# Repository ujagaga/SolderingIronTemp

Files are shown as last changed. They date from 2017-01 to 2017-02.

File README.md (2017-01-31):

# SolderingIronTemp

I made a simple circuit to controll GORDAK soldering iron temperature. I figured I don't really need excessive precision 
since I don't really notice much difference between 350 and 380 degrees when soldering and I only use two positions anyway,
colder for small SMDs and hotter for more massive pieces. i am very happy with how this works and it is extreemly cheap.
The PCB is made for DOT PCB Perfboard (2.5mm holle dostance) so no PCB printing is necessary. Resistors and capacitors are SMD 0805 and they fit 
nicelly between two dots and under the OpAmp.

The schematic and PCB was done in KiCad, but you can just use the PNG images.

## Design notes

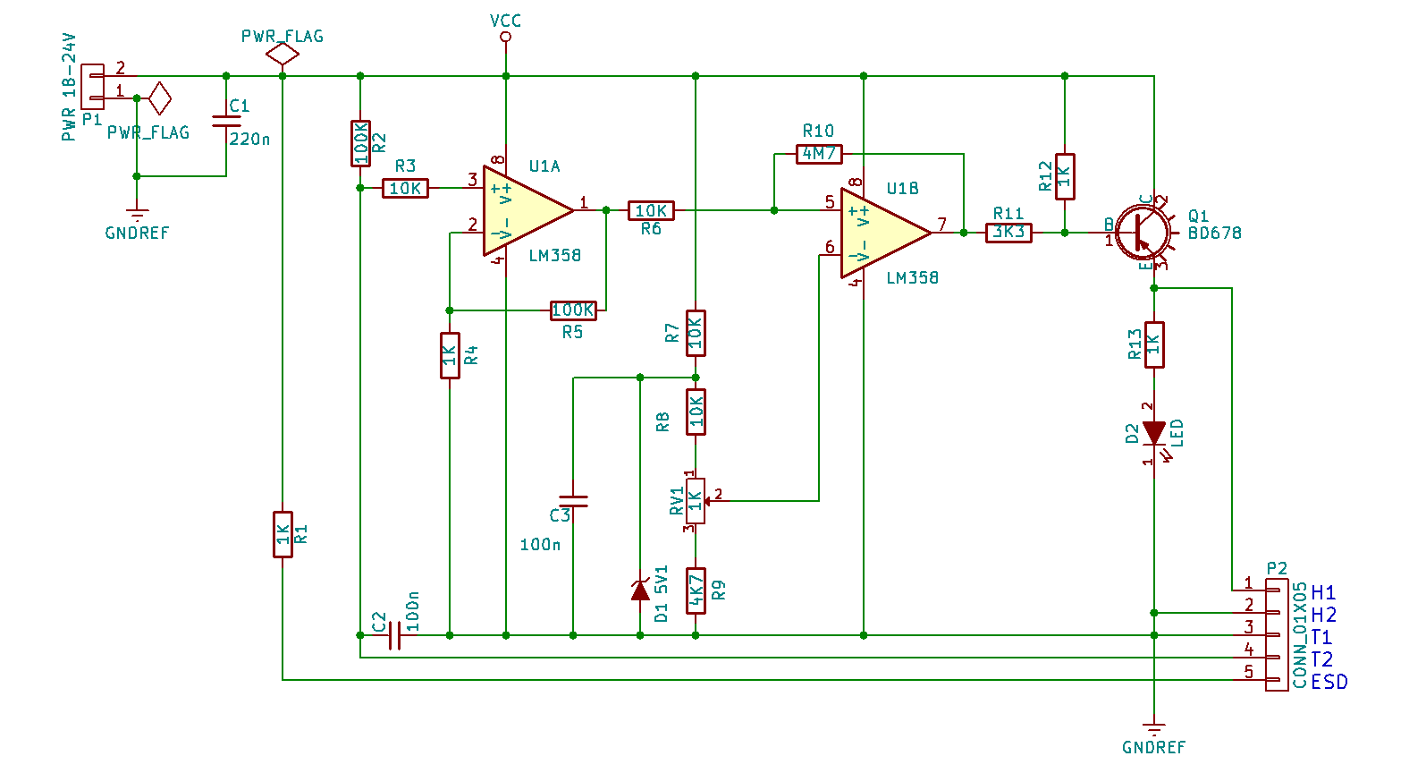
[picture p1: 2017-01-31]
Schematic.png

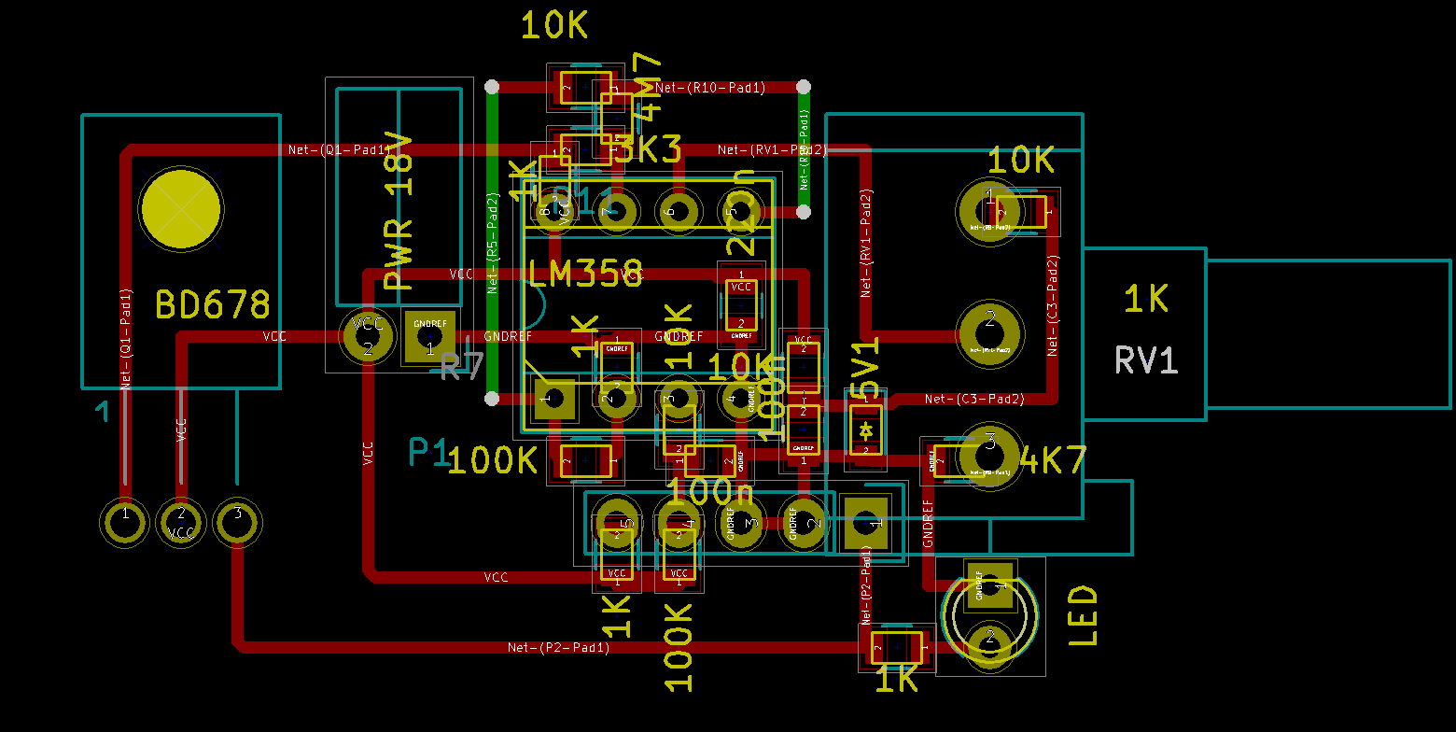
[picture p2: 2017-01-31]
PCB.png

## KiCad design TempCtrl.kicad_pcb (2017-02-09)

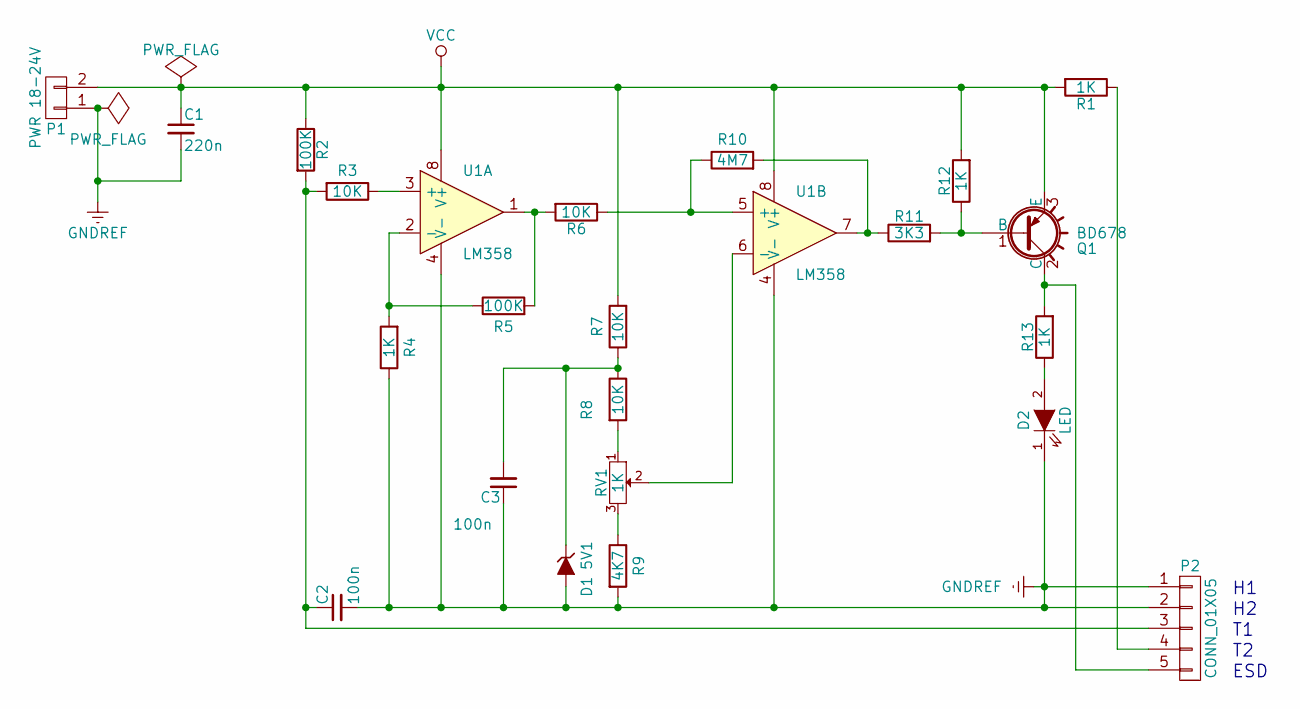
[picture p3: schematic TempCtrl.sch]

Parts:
C1: 220n; C_0805
C2, C3: 100n; C_0805
D1: 5V1; D_0805
D2: LED; LED_D3.0mm
P1: PWR 18-24V; Socket_Strip_Angled_1x02
P2: CONN_01X05; Socket_Strip_Straight_1x05
Q1: BD678; SOT126_SOT32_Housing_Horizontal
R1, R4, R12, R13: 1K; R_0805
R2, R5: 100K; R_0805
R3, R6, R7, R8: 10K; R_0805
R9: 4K7; R_0805
R10: 4M7; R_0805
R11: 3K3; R_0805
RV1: 1K; Potentiometer_Alps-RK16-single
U1: LM358; DIP-8_W7.62mm_Socket

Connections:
GNDREF: C1.2, C2.2, C3.1, D1.2 (A), D2.1 (K), P1.1, P2.1, P2.2, R4.1, R9.2, U1.4 (V-)
unnamed: C2.1, P2.3, R2.2, R3.2
unnamed: C3.2, D1.1 (K), R7.1, R8.1
unnamed: D2.2 (A), R13.1
unnamed: P2.4, R1.1
unnamed: P2.5, Q1.2 (C), R13.2
unnamed: Q1.1 (B), R11.2, R12.1
unnamed: R3.1, U1.3 (+)
unnamed: R4.2, R5.1, U1.2 (-)
unnamed: R5.2, R6.2, U1.1
unnamed: R8.2, RV1.1
unnamed: R9.1, RV1.3
unnamed: R6.1, R10.1, U1.5 (+)
unnamed: R10.2, R11.1, U1.7
unnamed: RV1.2, U1.6 (-)
VCC: C1.1, P1.2, Q1.3 (E), R1.2, R2.1, R7.2, R12.2, U1.8 (V+)

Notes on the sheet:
ESD

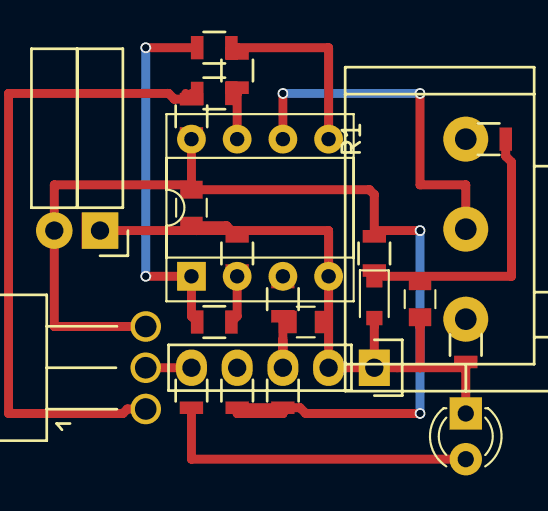
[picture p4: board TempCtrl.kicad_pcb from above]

Board: 2 copper layers, 23 parts (0 on the bottom side), 16 nets.

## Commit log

2017-01-29 * Schematic according to experiments * optimized PCB
    [TempCtrl.kicad_pcb, TempCtrl.sch]
2017-01-31 * changed schematic to use only one Darlington * Corrected the PCB accordingly
2017-01-31 Added PNG images
    [TempCtrl.kicad_pcb, TempCtrl.sch]
2017-02-09 Final version
    [TempCtrl.kicad_pcb, TempCtrl.sch]
